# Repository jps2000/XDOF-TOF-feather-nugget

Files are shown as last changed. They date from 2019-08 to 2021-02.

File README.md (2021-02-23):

# XDOF-TOF-feather-nugget
Feather nugget (piggyback PCB)  with BNO080/BNO055 IMU BMP388 Baro and VL53L1X tof sensor

Small PCB that fits to feather interface. Tested with nrf52832 BLE4.2
Features
-	9DOF IMU BNO080 or BNO055 optional
-	BMP388  Sensor for height measurements
-	TOF sensor VL53L1X up to 4 meters
-	1 neopixel status LED
-	ON/ OFF toggle button for battery use; USB auto on, shtdown from controller
-	Fits inside the feather footprint

Open source hardware, producers and suggestions welcome

feather nrf52832:  To achieve lowest battery current in off it is recommendend to remove the 100k pullup on EN (R5) and to replace the MBR120 shottky diode (D5) by a SI diode (1N4148).

The housing (not for TOF sensors)  is 3D printed. The cover should be made of transparent or translucent materials Use four screws ,Flat head, stainless steel 16mm long 2.2 mm diameter. The  battery is a Lipo size 502035 with 350mAh. Attention: wrong battery polarity destroys the feather. (Top view feather : GND = left VCC  = right)
Use a Kapton tape and double glue tape between the feather board and the battery.
The button can be made of a 2mm nylon Cylinder head screw colored with an Edding 3000 pen.

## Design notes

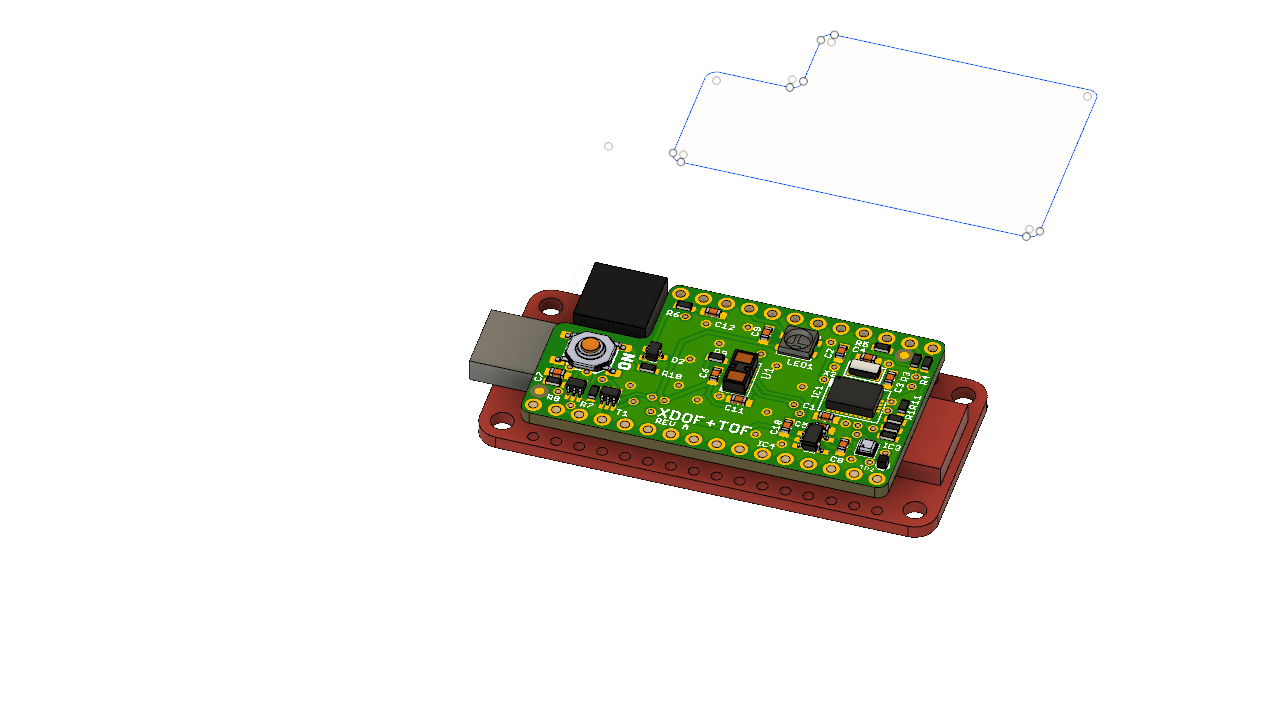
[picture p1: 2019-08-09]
top view.png

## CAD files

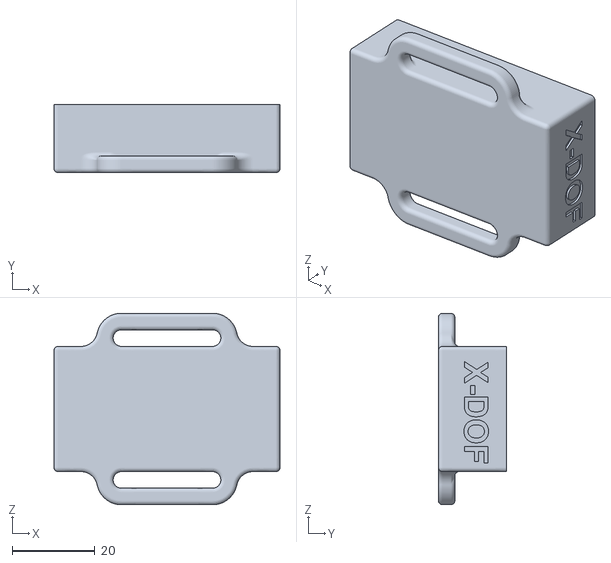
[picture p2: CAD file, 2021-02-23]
Bottom.stl
54.6 x 16.5 x 46.3

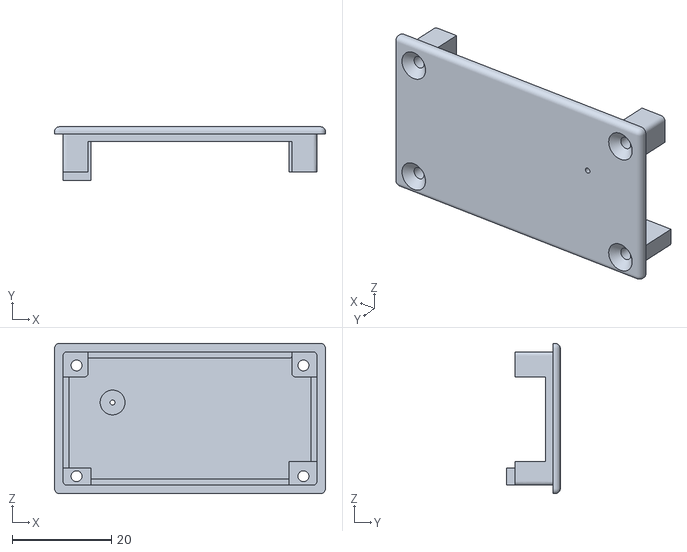
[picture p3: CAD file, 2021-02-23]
Cover.stl
54.6 x 10.8 x 30.3

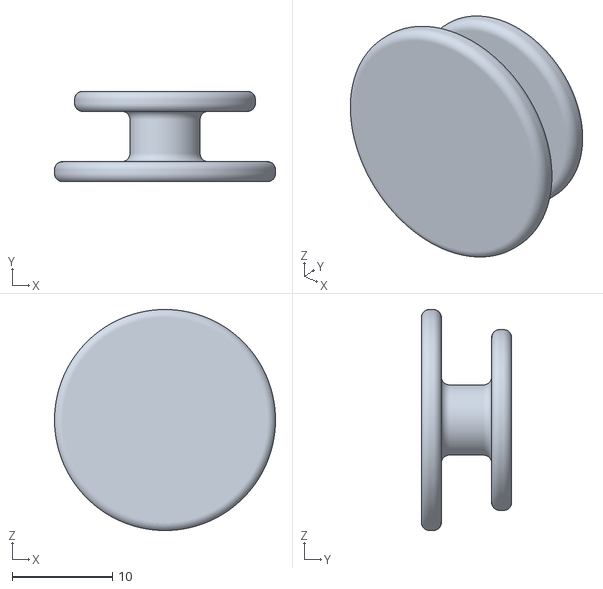
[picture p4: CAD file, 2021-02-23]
Button.stl
22.0 x 9.00 x 22.0

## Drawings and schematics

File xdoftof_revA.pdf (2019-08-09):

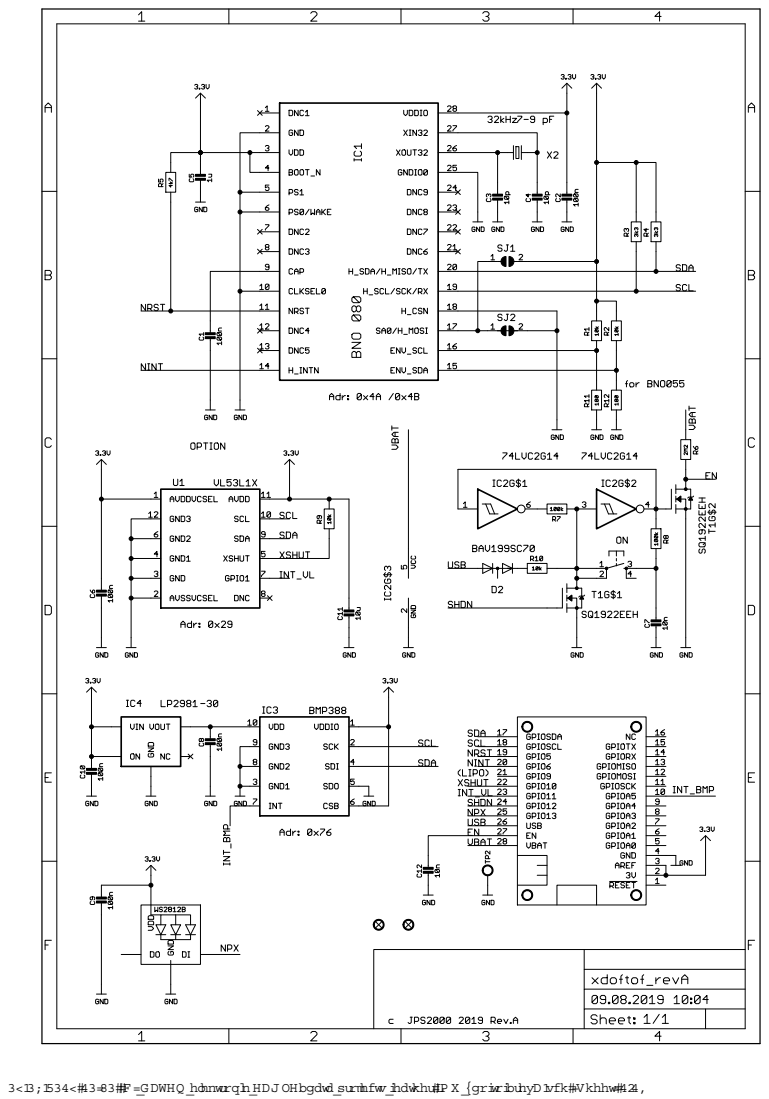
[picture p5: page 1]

09.08.2019 10:50 C:\D ATEN \elektronik\EAG LE_data\projects\feather IMU\xdoftof_revA.sch (Sheet: 1/1)

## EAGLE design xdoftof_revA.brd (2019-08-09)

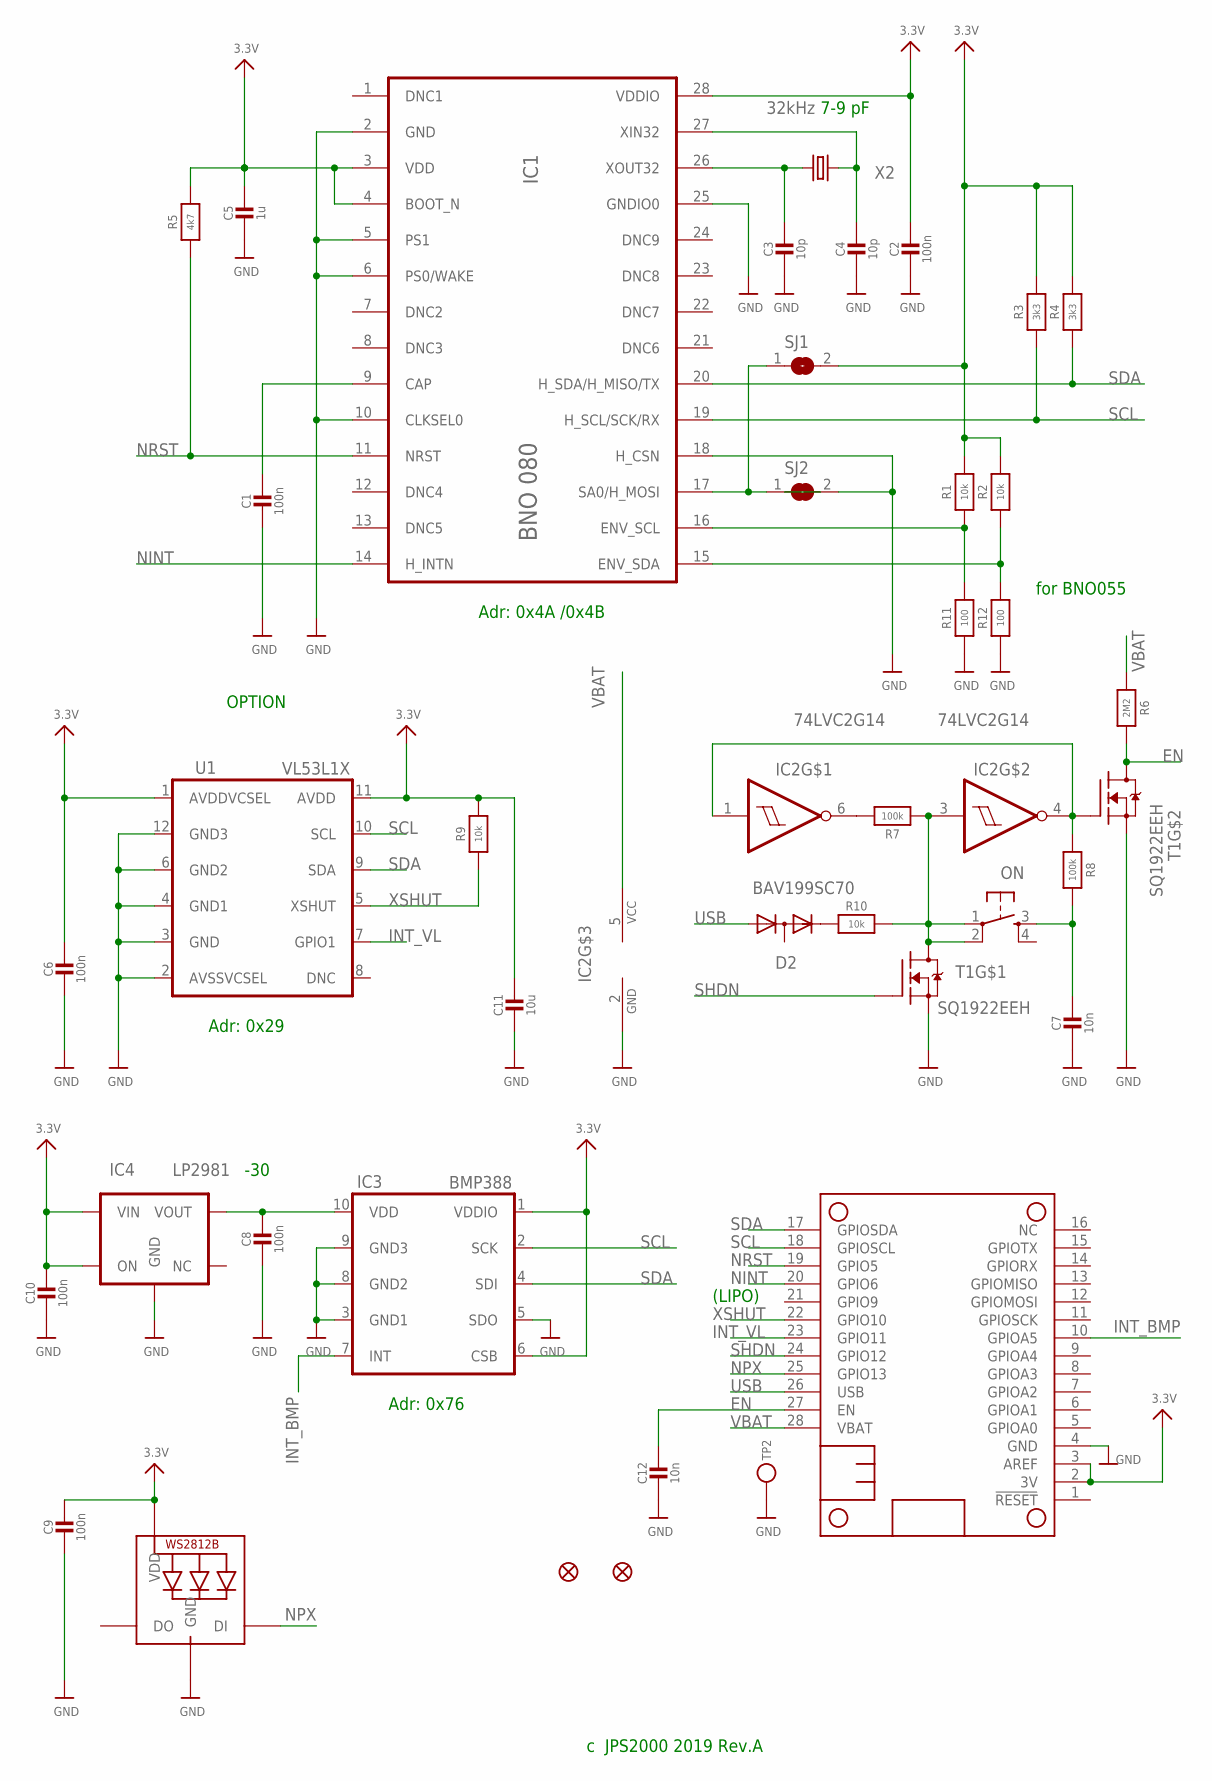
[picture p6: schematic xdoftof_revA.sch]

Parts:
C1, C2, C6, C8, C9, C10: 100n; 0603-NO
C3, C4: 10p; 0603-NO
C5: 1u; 0603-NO
C7, C12: 10n; 0603-NO
C11: 10u; 0603-NO
D2: BAV199SC70; SC70
FID1, FID2: FIDUCIAL""; FIDUCIAL_1MM
IC1: BNO080; LGA28
IC2: 74LVC2G14; SC70-6
IC3: BMP388; LGA10
IC4: LP2981; SOT23-5_NEW
LED1: WS2812B3535; LED3535
MS1: FEATHERWING_NOHOLES
ON: ON/OFF; TACTSWSKQGABE010
R1, R2, R9, R10: 10k; _0603MP
R3, R4: 3k3; _0603MP
R5: 4k7; _0603MP
R6: 2M2; _0603MP
R7, R8: 100k; _0603MP
R11, R12: 100; _0603MP
SJ1: SOLDERJUMPERREFLOW_NOPASTE; SOLDERJUMPER_REFLOW_NOPASTE
SJ2: SOLDERJUMPERCLOSED; SOLDERJUMPER_CLOSEDWIRE
T1: SQ1922EEH; SC70-6
TP2: TESTPOINTROUND1MM; TESTPOINT_ROUND_1MM
U1: VL53L1X
X2: 32kHz; XTAL_SMD1

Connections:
3.3V: C2.1, C5.1, C6.1, C9.1, C10.1, C11.1, IC1.3 (VDD), IC1.4 (BOOT_N), IC1.28 (VDDIO), IC3.1 (VDDIO), IC3.6 (CSB), IC4.P$1 (VIN), IC4.P$3 (ON), LED1.2 (VDD), MS1.2 (3V), MS1.3 (AREF), R1.2, R2.2, R3.2, R4.2, R5.2, R9.2, SJ1.2, U1.1 (AVDDVCSEL), U1.11 (AVDD)
EN: C12.1, MS1.27 (EN), R6.2, T1.3 (D)
GND: C1.2, C2.2, C3.2, C4.2, C5.2, C6.2, C7.2, C8.2, C9.2, C10.2, C11.2, C12.2, IC1.2 (GND), IC1.5 (PS1), IC1.6 (PS0/WAKE), IC1.10 (CLKSEL0), IC1.18 (H_CSN), IC1.25 (GNDIO0), IC2.2 (GND), IC3.3 (GND1), IC3.5 (SDO), IC3.8 (GND2), IC3.9 (GND3), IC4.P$2 (GND), LED1.4 (GND), MS1.4 (GND), R11.1, R12.1, SJ2.2, T1.1 (S), T1.4 (S), TP2.P$1, U1.2 (AVSSVCSEL), U1.3 (GND), U1.4 (GND1), U1.6 (GND2), U1.12 (GND3)
INT_BMP: IC3.7 (INT), MS1.10 (GPIOA5)
INT_VL: MS1.23 (GPIO11), U1.7 (GPIO1)
unnamed: C8.1, IC3.10 (VDD), IC4.P$5 (VOUT)
unnamed: C4.1, IC1.27 (XIN32), X2.P$2 (2)
unnamed: C3.1, IC1.26 (XOUT32), X2.P$1 (1)
unnamed: IC1.16 (ENV_SCL), R1.1, R11.2
unnamed: IC1.15 (ENV_SDA), R2.1, R12.2
unnamed: IC2.6 (O), R7.2
unnamed: C1.1, IC1.9 (CAP)
unnamed: D2.2 (C), R10.1
unnamed: IC2.3 (I), ON.1, ON.2, R7.1, R10.2, T1.6 (D)
unnamed: IC1.17 (SA0/H_MOSI), SJ1.1, SJ2.1
unnamed: C7.1, ON.3, R8.2
unnamed: IC2.1 (I), IC2.4 (O), R8.1, T1.5 (G)
NINT: IC1.14 (H_INTN), MS1.20 (GPIO6)
NPX: LED1.1 (DI), MS1.25 (GPIO13)
NRST: IC1.11 (NRST), MS1.19 (GPIO5), R5.1
SCL: IC1.19 (H_SCL/SCK/RX), IC3.2 (SCK), MS1.18 (GPIOSCL), R3.1, U1.10 (SCL)
SDA: IC1.20 (H_SDA/H_MISO/TX), IC3.4 (SDI), MS1.17 (GPIOSDA), R4.1, U1.9 (SDA)
SHDN: MS1.24 (GPIO12), T1.2 (G)
USB: D2.1 (A), MS1.26 (USB)
VBAT: IC2.5 (VCC), MS1.28 (VBAT), R6.1
XSHUT: MS1.22 (GPIO10), R9.1, U1.5 (XSHUT)

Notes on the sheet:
OPTION
(LIPO)
Adr: 0x76
7-9 pF
c JPS2000 2019 Rev.A
-30
Adr: 0x29
Adr: 0x4A /0x4B
for BNO055

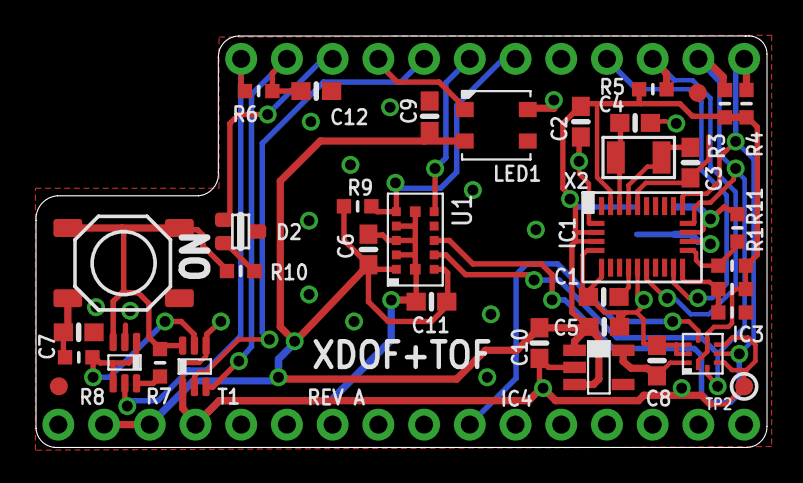
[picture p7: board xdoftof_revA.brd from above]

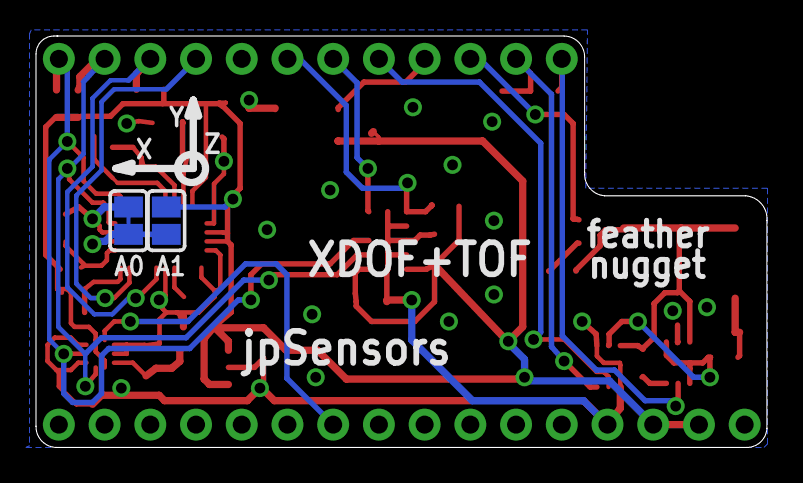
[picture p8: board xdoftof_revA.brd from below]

Board: 2 copper layers, 40.6 x 22.9 mm, 42 parts (3 on the bottom side), 26 nets.

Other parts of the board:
U$36, U$37: OPENSOURCE
